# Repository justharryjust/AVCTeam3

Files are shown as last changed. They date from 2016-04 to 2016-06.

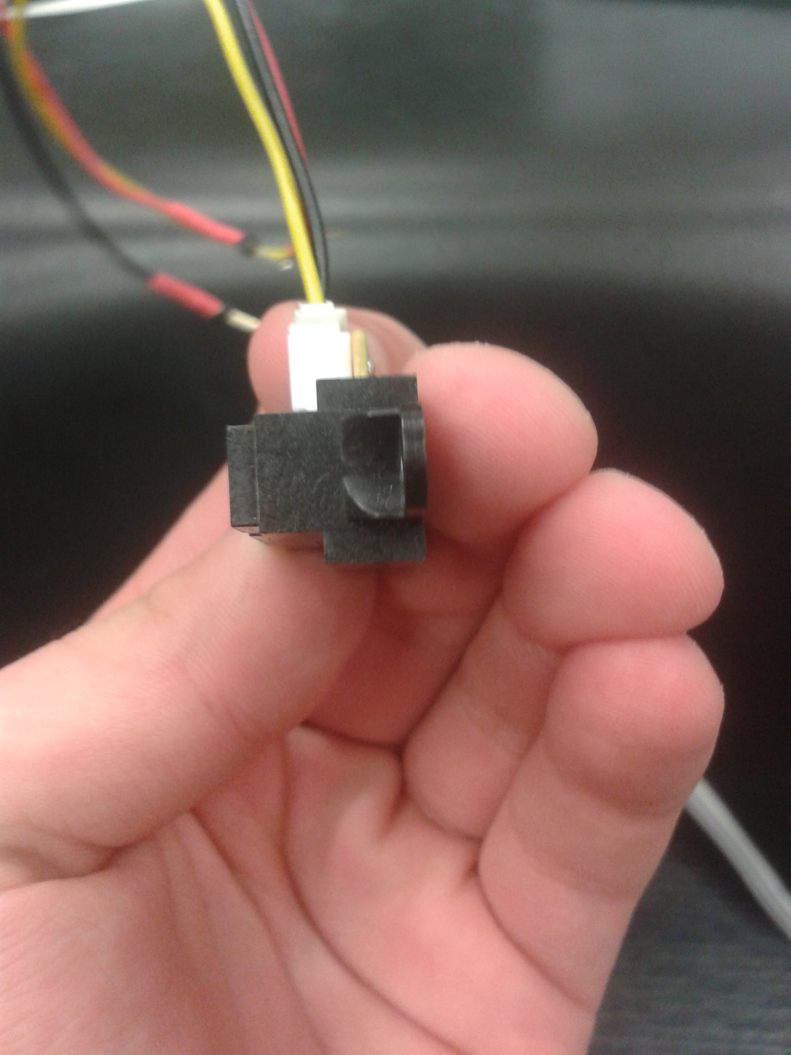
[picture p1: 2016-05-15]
Hardware/sensor2.jpg

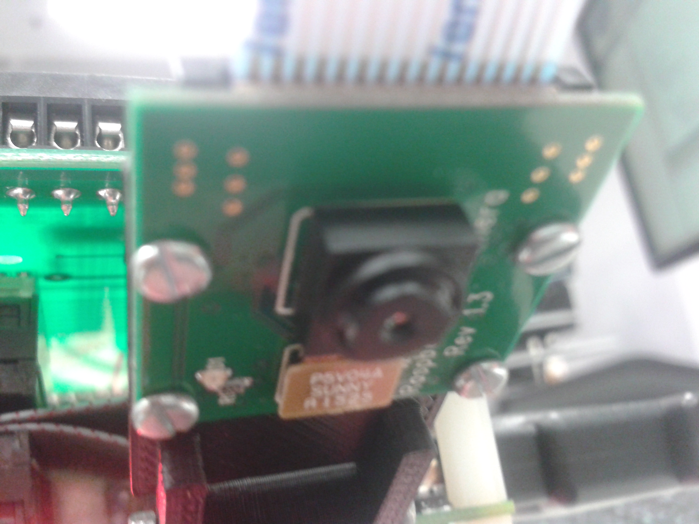
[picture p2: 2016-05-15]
Hardware/camera.jpg

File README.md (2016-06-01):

# AVCTeam3 - Apollo 100
Our project repository for the ENGR101 autonomous vehicle challenge (AVC) 2016.
Members:
- Thomas Edwards - Lead/Manager
- Julian Schurhammer - Software
- Nicky McCleery - Hardware 
- Harry Just - Hardware
- Adam Jiang - Software

###Week 1 Checklist
- [x] Thomas: Write up Plan in proper table
- [x] Thomas: Check all have signed aggreement 
- [x] Thomas: photo of maze uploaded
- [x] Thomas: Research error correction and code for following line
- [x] Julian: Produce code for straight line
- [x] Julian: Research PID and SSH
- [x] Adam: Help out Julian 
- [x] Adam: Research networking communication signal to open gate
- [x] Harry+Thomas: Setup team github repository
- [x] Nicky+Harry: Develop prototype chassis with pi
- [x] Nicky+Harry: Try assemble first prototype
- [x] Everyone: Add each other on facebook and set up group chat

##Week 1 review
Everyone did their assigned tasks, we got a group chat going and everyone successfully showed up to our lab. The initial default robot was assembled and we managed to get the robot's wheels to run successfully. This week hopefully we can get our robot following the line and get the basic robot design sorted. 

##Week 2 Checklist
- [x] Thomas: Review and record progress
- [x] Nicky+Harry: Work on making upgraded chassis prototype 2 which can turn easily (180mm space) and hold sensors
- [x] Julian: Work on code for making robot follow the white line
- [x] Adam: Work on code which will open the network gate
- [x] Thomas: Help work on code or if not needed help with prototype 2
 
##Week 2 review
Week 2 we managed to get the robot to follow the line, but it used the "reverse backwards" method instead of PID so hopefully we can change it in future to use PID. On the hardware side we managed to make some plans for our final robot design, these need to be uploaded to github, and used to write our reports. Networking code managed to be completed but hasnt been tested yet.

##Week 3 Checklist
- [x] Thomas: Review and record progress
- [x] Nicky+Harry: Work on chassis design and try to start building it.
- [x] Julian: Work on code for making robot follow the white line through intersections and turns
- [x] Adam: Finalise and test networking code, ensure it works as expected, try and merge it with line following code
- [x] Thomas: Help work on code or if not needed help with prototype
- Overall robot should: move forward, stop at gate, send network signal, wait till gate is opened, start doing line following code

##Week 3 Review
Week 3 we managed to design all of our hardware additional features including the battery holder, sensor holders and the 3rd ball wheel. We are waiting for the 3D printers to become available so we can print these off. Code wise, our robot now follows the line through the first 2 quadrants successfully using well tuned PID. We have planned out the code for the third quadrant but have yet to test and implement it.

##Week 4 Checklist
- [x] Thomas: Review and record progress
- [x] Harry: Have our marble holder/third wheel printed out and screwed on robot.
- [x] Harry: Create a proper battery holder to hold the battery securely
- [ ] Nicky: Have all our IR sensor holders printed out and screwed on
- [x] Julian: Finish code to make robot completly follow white lines through quadrant 3.
- [x] Thomas: Write code so that robot responds to the walls of maze:
- There are 3 sensors facing the front, left and right. At 45 degree angles
- Robot should follow Right Hand wall to get to the end. (Doesnt have to stop at the end)
- Robot will need to balance itself so that it is always a constant distance from Right wall.
- Robot will need to have a method to turn itself left 90 degrees.
- [x] Thomas: Write full maze code with help from Adam
- [x] Julian: Help with Maze code id line code fully complete

##Week 4 Review
Week 4 we are behind slightly, we have the ball holder but still waiting on the infared sensor holders to be printed or improvised. Changing our thirdwheel had an unexpected setback of changing our line following PID code. Retesting and tweaking this code for the new wheel is well underway and it's able to make it though the first two quadrants again. The code for quadrant three is still being tested and adjusted. The maze code has been written in a first draft but not tested. Extra hours will need to be put in from each team member for the robot to be upto scratch for the day.

##Week 5 The Day.
- [x] Everything should be done. All code merged into single file.
- [ ] No changes made on the day.
- [x] Maze Code all done and working.
- During this weeks lab we will have to show Arthur how far our robot can get through the maze.

##Week 5 Review
Week 5, this week alot of hardwork and effort was put in by the team. The maze code managed to be completed and tested, the hardware was fully completed and everything was securely fastened in place. The hardwork paid off and we managed to make it through 100% of the course on the first try (Amazing), despite our practise runs only making it through about 30% of the time. The only change we made on the day was to uncomment our Network code. Our chassis broke during a test run that went wrong however by using another piece of chassis and some screws we were able to fix it.

##General Plan
 - First Week: Assign Roles, assemble basic robot, get it moving
 - Second Week: Robot moves through gate and in straght lines and turns, (Quadrant 1)
 - Third Week: Robot should be able to follow tape (Quadrant 2)
 - Fourth Week: Robot should be able to follow tape through right angle intersections and turns (Quadrant 3)
 - Fifth Week onwards: Work on Challenge part (Quadrant 4). Finnalise any code/hardware needing work

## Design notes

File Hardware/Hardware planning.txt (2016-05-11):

Hardware design specifications:

Hold the infrared sensors
  Encase the pi and hold it
  Be able to turn in the maze which is 180mm
  Look sleek and cool (optional)
  Be recyclable/relatively environmentally friendly

5mm between the centre of holes
Holes are 3mm each

Objectives
  3d print the ball and holder
  3d print the infared senor holders
  Potentially 3d print a case.

Designs on paper or CAD done by saturday.

Nicky:
  sensor holders
  
Harry:
  ball and holder

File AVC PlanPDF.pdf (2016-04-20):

AVC Plan

Robot name: Apollo 100

Team members and roles (Note. we all plan to help on all things so roles are only a rough guideline):

-Thomas Edwards - Lead/Manager

-Julian Schurhammer - Software

-Nicky McCleery - Hardware

-Harry Just - Hardware

-Adam Jiang – Software

Our full plan and weekly up to date progress can be found on Git hub

Link to Team GitHub: https://github.com/harryJst/AVCTeam3

Week | Dates | Team Objectives | Due | Conflicts | Task outline
1 | 18April | Organise everything | 22 April AVC PLAN | Phys 122 test | • Thomas- Organise things and set up Git Page • Julian - Write test code for moving robot • Nicky & Harry - Build first chassis • Adam - Gather info on networking gate • Everyone- Facebook and group chat
Holiday | 25April | Finish off Week 1 tasks if not done
2 | 2May | Have the robot moving through networking gate | | | • Thomas- Review and write up progress & help • Julian - Write test code for following white line • Nicky & Harry - Work on upgrading chassis • Adam - Write code for networking gate
3 | 9May | Have the robot chassis design finalised and have the robot following white line Quadrant 2 complete | | Comp 102 test | • Thomas- Review and write up progress & help • Julian - Write test code for turning with white line • Nicky - Work on chassis or help with code • Harry - Work on chassis or help with code • Adam - Help with code for turning and overcoming intersections
4 | 16May | Quadrant 3 complete | Progress Report | ENGR 121 test | • Update results, work on quadrant 3
5 | 23May | Quadrant 4 complete | | | • Update results, work on quadrant 4
6 | 30May | Everything complete | ROBOT due | ENGR 101 test | • Update results, work on anything if behind
7 | 6June
8 | 13June | | Final Report due

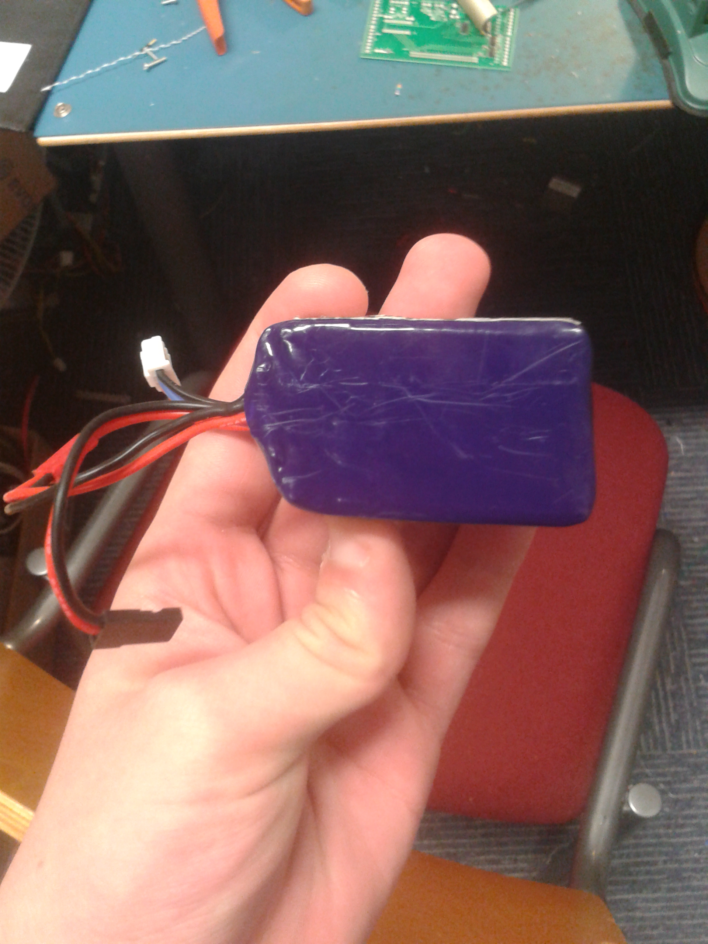
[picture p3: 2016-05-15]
Hardware/battery2.jpg

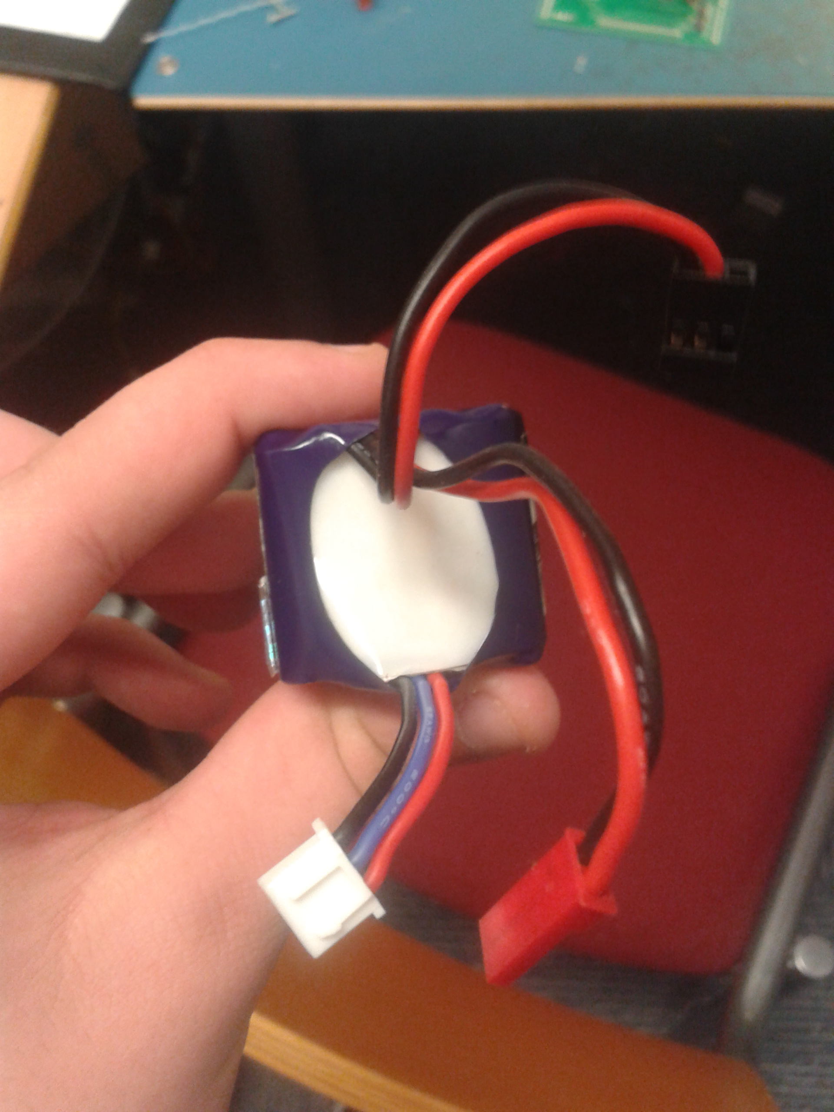
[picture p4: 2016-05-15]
Hardware/battery1.jpg

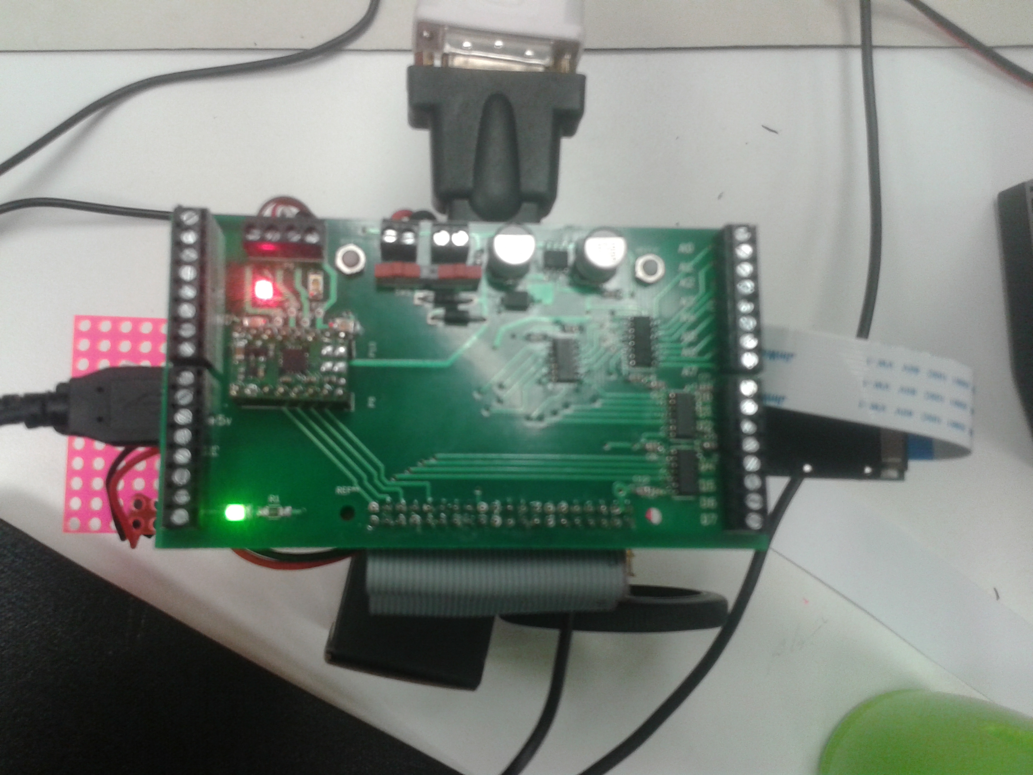
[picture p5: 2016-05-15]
Hardware/toprobot.jpg

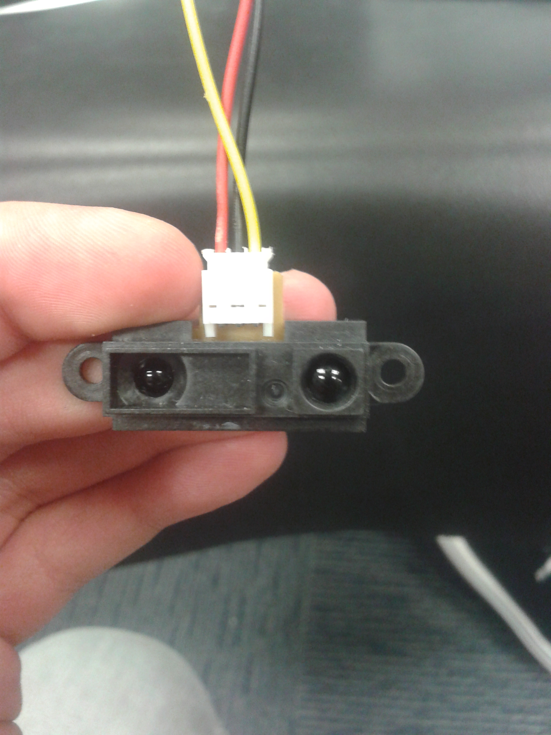
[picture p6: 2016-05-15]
Hardware/sensor1.jpg

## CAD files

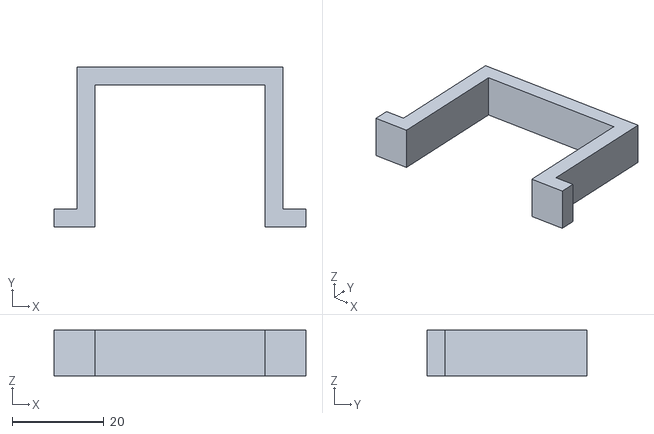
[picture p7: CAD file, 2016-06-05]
Hardware/Final_Battery_holder.stl
55.0 x 35.0 x 10.0

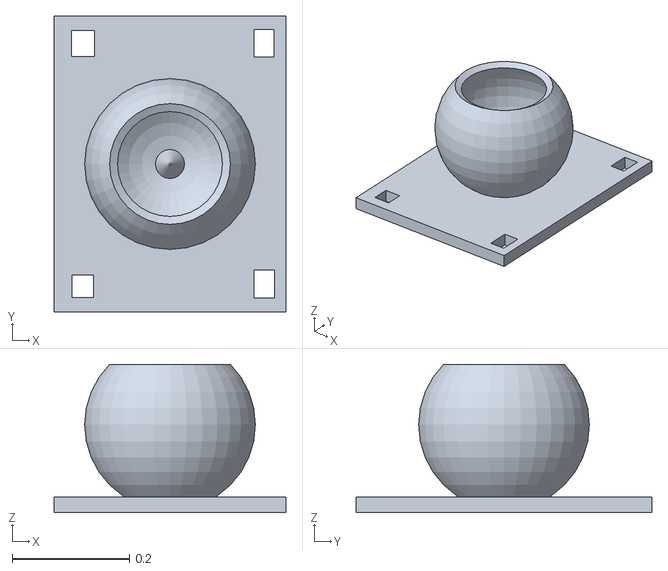
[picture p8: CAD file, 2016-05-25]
Pictures/WHEEL_HOLDER.stl
0.395 x 0.504 x 0.253

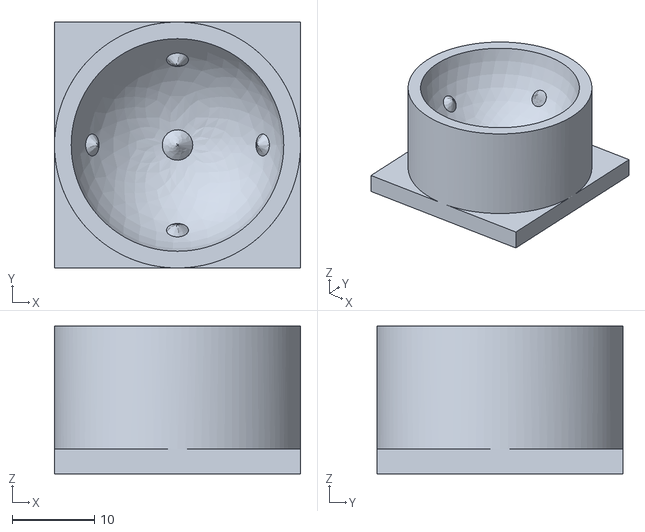
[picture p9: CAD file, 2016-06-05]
Hardware/mesh_to_print_wheel.stl
30.0 x 30.0 x 18.0

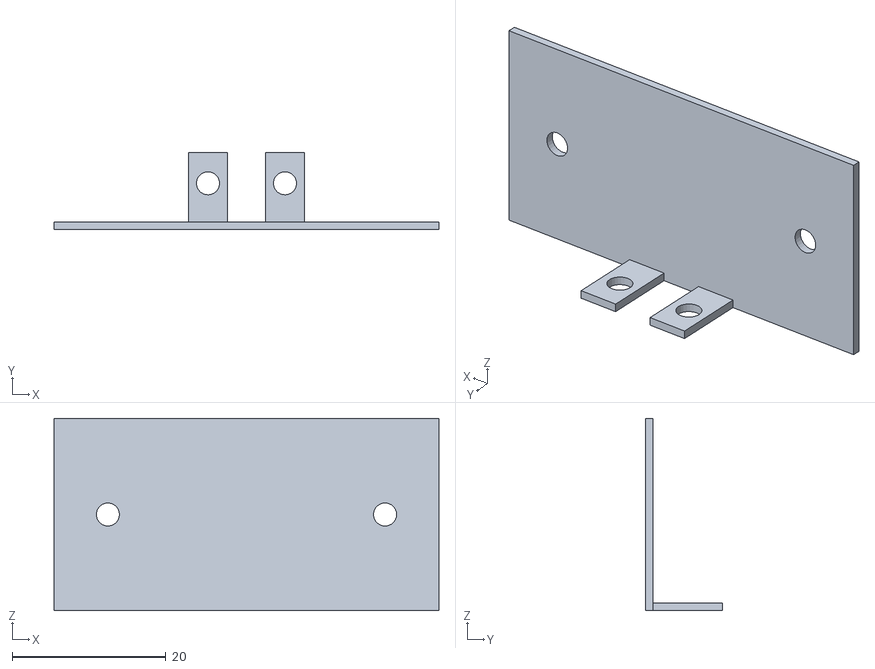
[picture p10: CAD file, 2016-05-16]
Pictures/IR sensorHolderV2.stl
50.0 x 10.0 x 25.0

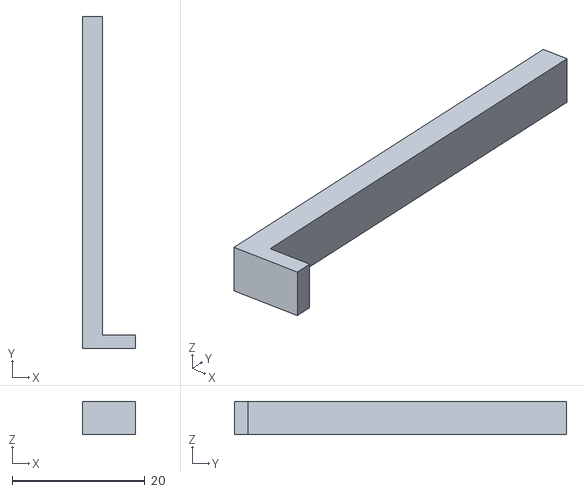
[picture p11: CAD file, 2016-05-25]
Hardware/Lbracket.stl
8.00 x 50.0 x 5.00

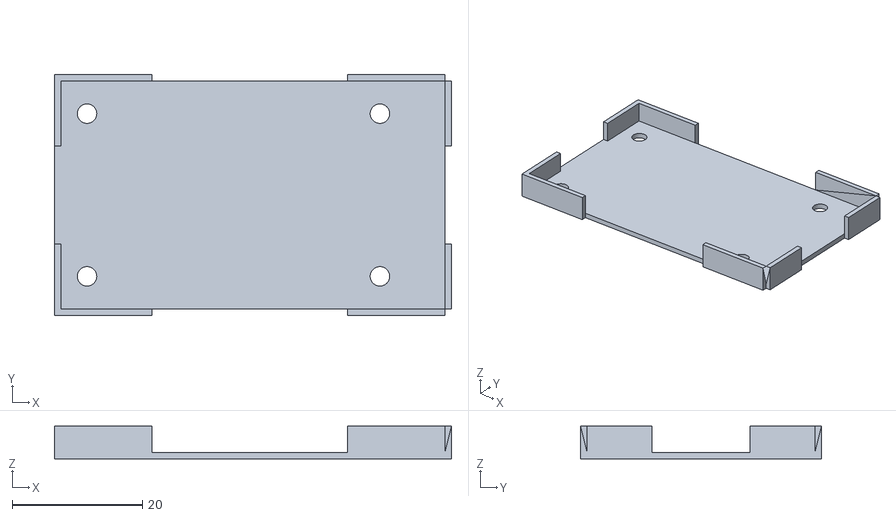
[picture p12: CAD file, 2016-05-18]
Hardware/Batt Holder.stl
61.0 x 37.0 x 5.00

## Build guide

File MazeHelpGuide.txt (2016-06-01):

How the maze code Starts:

The maze code is initialised when the right hand sensor detects an object closer than about 5cm. To avoid this triggering when 
going through the network gate, there is also a counter which moves up every time the robot moves. Only once the robot has moved
about halfway through the course will it start taking readings from the sensors.

How the maze code works:

Maze code is quite simple, there are only  two sections of it. The first section is a loop which loops forever, this loop simply 
takes a distance reading of the right hand wall,  does some math (subtracts 400 then multiplies by 0.15) and sets the motors to that 
resulting number. If the number is positive then the left motor will move more than the right and if negative vice versa. This code 
enables the robot to follow the right hand wall through straight paths and also right turns (as when no wall is detected on the right,
resulting number becomes very negative causing a sharp right turn until a wall is detected again).
The second piece of code is simply a hard coded left turn method, it is called whenever the front sensor detects a wall closer than 5cm. 
It simply codes the left wheel to stop and the right wheel to spin for 0.7 seconds which creates a perfect left turn. The code then 
returns to following the right wall.

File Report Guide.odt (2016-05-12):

Report

guide here:

https://github.com/kaiwhata/ENGR101-2016/wiki/Report-Writing-guide

Aim: To build a functioning robot that will follow a white line through curves and intersections, it will then get to a maze section without a white line and successfully navigate its way to the end of the maze.

Possible Motivations:

Practise working in a team

Beat other teams.

Gain skills in working on long term projects such as time managing, breaking tasks up etc.

Increase communications skills.

Good grades

Self fulfilment.

Software:

Problem to be solved:

- Robot loses the line when it oscillates when following it, and then keeps going forward. As error signal is 0 when all black.
  What we’ve done:
- Takes all pixels along one line, puts them into an array
- if the greyscale of the pixels are darker than a certain value, then they are black otherwise they are white.
- Amount of whiteness which is detected that is not centred will create a plus/minus error signal
- Error signal is used to control speed of each wheel. So that it turns proportionate to how off centred line is.
- Implemented PID into code to follow line. Haven’t managed to get it working perfectly yet.

Hardware:

3d printing complex shapes harder than expected

Built basic chassis so that code can be tested before final model is built

Sketches for cases done, best design still to be chosen

Model for back wheel/ball designed, temporary marble in place atm

Camera held securely in place at front so that there isn’t any jiggling when robot moving

Using large wheels (pros/cons)

Network:

Written code to open gate through wifi.

Need to write code to use sensor to stop/start when gate closed/open

This code possibly can be used in the maze as well.

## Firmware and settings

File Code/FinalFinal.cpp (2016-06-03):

#include<iostream> 
#include<stdio.h> 
#include<time.h> 
#include<chrono> 
#include<cstdlib> 
#include<signal.h>

extern "C" int init(int d_level);
extern "C" int Sleep(int sec, int usec);
extern "C" int set_motor(int motor, int value);
extern "C" int take_picture();
extern "C" int get_pixel(int row, int col, int colour);
extern "C" int open_screen_stream();
extern "C" int close_screen_stream();
extern "C" int update_screen();
extern "C" int connect_to_server(char server_addr[15], int port);
extern "C" int send_to_server(char message[24]);
extern "C" int receive_from_server(char message[24]);
extern "C" int read_analog(int ch_adc);
extern "C" int set_pixel(int row, int col, char red, char green, char blue);

using namespace std;
using namespace std::chrono;

const int white_value = 110;
const int camera_y_coord = 0;
const int min_line_width = 25;
const float speed = 0.9; // working value 0.9
const int speed1 = 60; // speed for maze code
bool run_sensor = true;
float P = 0.28; // working value 0.28
float I = 0.0; // working value 0.0
float D = 50; // working value 50
float max_error = 160; // working value 160

// This method is called when the program exists
void signal_callback_handler(int signum)
{
    set_motor(1, 0);
    set_motor(2, 0);
    exit(signum);
}

// Return the error signal from the current picture
int error_method_4(int cam_y)
{
    int min = 0;
    int consec_white_pixels = 0;
    for (int i = 0; i < 320; i++) { // Loop through line of pixels at given y coord
        int value = get_pixel(i, cam_y, 3);
        if (value > white_value) { // If the pixel is white
            consec_white_pixels += 1; // Increate the consecutive pixel counter
            if (consec_white_pixels >= min_line_width) { // If there are enough white pixels
                min = i - consec_white_pixels; // Set min to where the consecutive pixels started
                break; // Stop the loop
            }
        }
        else { // If the pixel is black
            consec_white_pixels = 0; // Reset the pixel counter
        }
    }
    int max = 0;
    consec_white_pixels = 0;
    for (int i = 320; i >= 0; i--) { // Loop through the line of pixels again, this time 
        int value = get_pixel(i, camera_y_coord, 3); // back to front
        if (value > white_value) { // if the pixels is white
            consec_white_pixels += 1; // increate the counter
            if (consec_white_pixels >= min_line_width) { // if the counter is big enough
                max = i + consec_white_pixels; // Set min to where the consecutive pixels started
                break; // Stop the loop
            }
        }
        else { // If pixel si black
            consec_white_pixels = 0; // Reset the pixel counter
        }
    } 
    // Return the average of the min and max point of the line, ie the middle,
    // and set subtract 160 so that the signal is 0 in the center of the picture,
    return ((min + max) / 2) - 160; // -ive to the left and +ive to the right.
}

// Restrict val between a and b
int clamp(int a, int b, int val)
{
    if (val < a) {
        return a;
    }
    if (val > b) {
        return b;
    }
    return val;
}

// Return the current time stamp in miliseconds as a long
long get_time()
{
    return duration_cast<milliseconds>(system_clock::now().time_since_epoch()).count();
}

// Draw what the camera is seeing on screen in black & white
void print_picture()
{
    for (int i = 0; i < 240; i++) {
        for (int j = 0; j < 320; j++) {
            int value = get_pixel(j, i, 3);
            if (value > white_value) {
                set_pixel(j, i, 255, 255, 255);
            }
            else {
                set_pixel(j, i, 0, 0, 0);
            }
            if (i == 0) {
                set_pixel(j, i, 200, 0, 0);
            }
        }
    }
    update_screen();
}

// Return true if there is a sharp right turn
bool line_on_right()
{
    int white_pixels = 0;
    for (int i = 0; i < 160; i++) { // Loop from the right to the middle of the picture
        int value = get_pixel(i, camera_y_coord, 3);
        if (value > white_value) { // if the pixel is white
            white_pixels += 1; // add to the pixel counter
        }
        if (white_pixels > 150) { // if 150/160 pixels are white
            return true; // there is a sharp right turn, return true
        }
    }
    return false; // return false otherwise
}

// Return true if there is a sharp left turn
bool line_on_left()
{
    int white_pixels = 0;
    for (int i = 160; i < 320; i++) { // Loop from the middle to the left of the picture
        int value = get_pixel(i, camera_y_coord, 3);
        if (value > white_value) { // if the pixel is white
            white_pixels += 1; // add to the pixel counter
        }
        if (white_pixels > 150) { // if 150/160 pixels are white
            return true; // there is a sharp left turn, return true
        }
    }
    return false; // return false otherwise
}

// Return true the robot is at an intersection
bool is_at_intersection()
{
    int white_pixels = 0;
    for (int i = 0; i < 320; i++) { // Loop through a line on the picture
        int value = get_pixel(i, camera_y_coord, 3);
        if (value > white_value) { // if the pixel is white
            white_pixels += 1; // add to the pixel counter
        }
        if (white_pixels > 300) { // if 300/320 pixels are white
            return true; // there is an intersection, return true
        }
    }
    return false; // return false otherwise
}

// Return true if there is a line to make an error signal
bool is_line_there(int camera_y)
{
    int consec_white_pixels = 0;
    for (int i = 0; i < 320; i++) { // Loop through a line on the picture
        int value = get_pixel(i, camera_y, 3);
        if (value > white_value) { // if the pixel is white
            consec_white_pixels += 1; // add to consecutive pixel counter
            if (consec_white_pixels >= min_line_width) { // if the counter is big enough
                return true; // return true, there is a line there
            }
        }
        else { // if the pixel is black
            consec_white_pixels = 0; // reset the counter
        }
    }
    return false;
}

int integral = 0;
int last_error = 0;
long last_loop_end_time = 0;
// Do one iteration of the line following code
void follow_loop()
{
    take_picture(); // Take a new picture
    int error = 0;
    if (is_line_there(camera_y_coord)) { // if there is a line
        error = error_method_4(camera_y_coord); // get the error signal from that line
    }
    else { if there is no line (lost the line)
        if (last_error > 0) { // if the last error was > 0
            error = max_error; // set the error to the maximum error
        }
        else { // otherwise
            error = 0 - max_error; // set the error to negative of the maximum error
        }
    }
    if (is_at_intersection()) { // If the robot is at an intersection
        if (is_line_there(220 /*220 = pixel near top */)) { 
            //If there is a going line forward
            error = error_method_4(220); // get error based on that line
        }
        else { // otherwise
            error = max_error; //go left
        }
    }
    else if (line_on_left()) {// If the robot is at a sharp left turn
        if (is_line_there(220 /*220 = pixel near top */)) {
            error = error_method_4(220); // get error based on that line
        }
        else { // otherwise
            error = max_error; //go left
        }
        error = max_error;
    }
    else if (line_on_right()) { // If the robot is at a sharp right turn
        if (is_line_there(220 /*220 = pixel near top */)) {
            error = error_method_4(220); // get error based on that line
        }
        else { // otherwise
            error = 0 - max_error; //go right
        }
    }
    print_picture(); // print out the current picture
    integral += error; // the integral is the runing total of errors
    long time = get_time(); // get the current timestamp
    // The derivative is change in error over change in time
    float derivitive = ((float)(error - last_error)) / ((float)(time - last_loop_end_time));
    last_loop_end_time = time; // set the last end time to the current time
    last_error = error; // set last error to current error
    int final_signal = P * error + I * integral + D * derivitive; // make the final signal using PID constants
    cout << "error " << error << endl; // print out the error for debugging
    cout << "integral " << integral << endl; // print out the integral for debugging
    cout << "derivitive " << derivitive << endl; // print out the derivitive for debugging
    cout << "final " << final_signal << endl; // print out the final signal for debugging
    // set the motor speeds to a value that iss  50 +- the final signal, but also between -100 and 150
    set_motor(1, speed * clamp(-100, 150, 50 + final_signal));
    set_motor(2, speed * clamp(-100, 150, 50 - final_signal));
}

// main method, run when the program is started
int main()
{
    init(0); // initialise the e101 library
    open_screen_stream(); // open the stream for printing the picture on the screen

    connect_to_server("130.195.6.196", 1024); // connect to the gate server
    send_to_server("Please"); // send "Please" to the gate sever
    char pswd[24]; // Create a char array to store the password
    receive_from_server(pswd); // Get the password from the sever and store it
    send_to_server(pswd); // Send the password back to the server

    int count = 0; // a counter for delaying the activation of the maze code
    last_error = error_method_4(0); // initialise the last error variable
    last_loop_end_time = get_time(); // initialise the loop end time variable
    while (true) { // repeat forever
        int sen3 = read_analog(2); // read the right ir sensor
        int sen1 = read_analog(1); // read the left ir sensor
        int sen2 = read_analog(0); // read the middle ir sensor
        count++;
        if (sen3 < 300 && sen1 < 300) { // if the sensors dont see anythign close
            follow_loop(); //follow the line
        }
        else if (sen2 > 300) { // if the middle sensor seed something close
            set_motor(1, 0); // stop the motor
            set_motor(2, 0); // stop the other motor
            last_loop_end_time = get_time(); // set the last loop time
        }
        else if ((sen3 > 400 || sen1 > 400) && sen2 < 300 && count > 200) {
            while (1) {
                int sen1 = read_analog(1); // read the left ir sensor
                int sen2 = read_analog(0); // read the middle ir sensor
                int sen3 = read_analog(2); // read the right ir sensor

                int dif = sen3 - 400; //distance from right hand wall (Smaller is a great distance)
                if (dif < -220) {
                    dif = -220;
                } //sharpness of turn (smaller is less sharp)
                dif = dif * 0.15; //how responsive robot is
                set_motor(1, speed1 + dif);
                set_motor(2, speed1 - dif);

                if (sen2 > 220 && sen3 > 200) { //turning Left method
                    set_motor(1, 0);
                    set_motor(2, 0);
                    Sleep(1, 0);
                    set_motor(1, speed1 + 40); //speed of turn
                    set_motor(2, 0);
                    Sleep(0, 600000); //turn duration
                }
            }
        }
    }

    return 0;
}

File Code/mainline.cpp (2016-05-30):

#include <iostream>
#include <stdio.h>
#include <time.h>
#include <chrono>

extern "C" int init(int d_level);
extern "C" int Sleep(int sec, int usec);
extern "C" int set_motor(int motor, int value);
extern "C" int take_picture();
extern "C" int get_pixel(int row, int col, int colour);
extern "C" int open_screen_stream();
extern "C" int close_screen_stream();
extern "C" int update_screen();
extern "C" int connect_to_server( char server_addr[15],int port);
extern "C" int send_to_server(char message[24]);
extern "C" int receive_from_server(char message[24]);
extern "C" int read_analog(int ch_adc);
extern "C" int set_pixel(int row, int col, char red, char green, char blue);

using namespace std;
using namespace std::chrono;

//PID coefficients
const float P = 0.28;
const float I = 0.0;
const float D = 50;

//Other constants
const int white_value = 110;
const int min_line_width = 40;
const float speed = 0.9;

//Restrict val between a and b
int clamp(int a, int b, int val){
	if(val < a){
		return a;
	}
	if(val > b){
		return b;
	}
	return val;
}

long get_time(){
	return duration_cast<milliseconds>(system_clock::now().time_since_epoch()).count();
}

void print_picture(){
	for(int i = 0; i < 240; i++){
		for(int j = 0; j < 320; j++){
			int value = get_pixel(j, i, 3);
			if(value > white_value){
				set_pixel(j, i, 255, 255, 255);
			} else {
				set_pixel(j, i, 0, 0, 0);
			}
		}
	}
	update_screen();
}

int get_error(int y_value){
	int min = 0;
	int consec_white_pixels = 0;
	for(int i = 0; i < 320; i++){
		int value = get_pixel(i, y_value, 3);
		if(value>white_value){
			consec_white_pixels += 1;
			if(consec_white_pixels >= min_line_width){
				min = i - consec_white_pixels;
				break;
			}
		}
		else {
			consec_white_pixels = 0;
		}
	}
	int max = 0;
	consec_white_pixels = 0;
	for(int i = 320; i >=0; i--){
		int value = get_pixel(i, y_value, 3);
		if(value>white_value){
			consec_white_pixels += 1;
			if(consec_white_pixels>=min_line_width){
				max = i + consec_white_pixels;
				break;
			}
		} else {
			consec_white_pixels = 0;
		}
	}
	return ((min + max)/2)-160;
}

bool vertical_line(int y_coord){
	int consec_white_pixels = 0;
	for (int i = 0;i<320;i++) {
		int value = get_pixel(i, y_coord, 3);
		if (value>white_value) {
			consec_white_pixels += 1;
			if(consec_white_pixels >= min_line_width){
				return true;
			}
		} else {
			consec_white_pixels = 0;
		}
	}
	return false;
}

bool is_intersection(int y_coord){
	int consec_white_pixels = 0;
	for (int i = 0;i<320;i++) {
		int value = get_pixel(i, y_coord, 3);
		if (value>white_value) {
			consec_white_pixels += 1;
			if(consec_white_pixels >= 200 /* 200 = 80% are white*/){
			return true;
		}
	} else {
		consec_white_pixels = 0;
	}
}
return false;
}

bool horizontal_line(int x_coord){
	int consec_white_pixels = 0;
	for (int i = 0;i<240;i++) {
		int value = get_pixel(x_coord, i, 3);
		if (value>white_value) {
			consec_white_pixels += 1;
			if(consec_white_pixels >= min_line_width){
				return false;
			}
		} else {
			consec_white_pixels = 0;
		}
	}
	return true;
}



//Initial values
int integral = 0;
int last_error = 0;
long last_loop_end_time = 0;
void follow_line(){
	take_picture();

	print_picture();
	if(is_intersection(0)){
		if(vertical_line(230 /* 230y = top pixel */)){

		} else if (horizontal_line(0 /* 0x = left pixel */)){

		} else if (horizontal_line(310 /* 310x = top pixel */)){

		}
	} else if(vertical_line(0 /* 0y = bottom pixel */);){
		//if there is a lineon the bottom pixel, get the error from it
		int error = get_error(0 /* 0 = bottom pixel */);
	} else {
		//lost the line
		error = last_error;
	}

	integral += error;
	long time = get_time();
	float derivitive = ((float)(error - last_error))/((float)(time - last_loop_end_time));
	last_loop_end_time = time;
	last_error = error;

	int final_signal = P*error + I*integral + D*derivitive;

	//Remove clamp?
	set_motor(1 , speed*clamp(-100, 150, 50+final_signal));
	set_motor(2 , speed*clamp(-100, 150, 50-final_signal));
}

int main()
{
	init(0);
	open_screen_stream();

	//    connect_to_server("130.195.6.196",1024);
	//    send_to_server("Please");
	//    char pswd[24];
	//    receive_from_server(pswd);
	//    send_to_server(pswd);

	int adc_reading = 0;
	last_error = get_error();
	last_loop_end_time = get_time();
	while(true){
		adc_reading = read_analog(0);
		if(adc_reading<400){
			//Follow the line
			follow_line();
		} else {
			//Stop
			set_motor(1 , 0);
			set_motor(2 , 0);
			last_loop_end_time = get_time();
		}
	}
	return 0;
}

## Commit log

2016-05-04 Camera test
2016-05-05 Code tested, follows line, gets stuck occasionally
    Next step is make robot adjust its direction slightly when it move backward, possibly just random adjustment or adjustment based on whether it lost line to the left or the right.
    [tom camera test.cpp]
2016-05-05 when reversing, it turns slightly
    updated code so that when it moves backwards it turns slightly. This should prevent it from getting stuck
    [tom camera test.cpp]
2016-05-16 IR Sensor Mounting Bracket
    [IR Hplder v2.stl]
2016-05-18 Create 3d printing
2016-05-18 3d printing parts
    [Batt Holder.stl, IR Hplder v2.stl]
2016-05-18 new PID code
2016-05-25 Add files via upload
    final hardware parts
    [Lbracket.stl, WHEEL_HOLDER.stl]
2016-05-30 Cleaned up files
    [Batt Holder.stl, IR Hplder v2.stl, Lbracket.stl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]
2016-05-30 Updated more names
    [IR sensorHolderV2.stl]
2016-06-05 Final back wheel design
    the final design that was printed for the robot
    [mesh_to_print_wheel.stl]
2016-06-05 Final Battery holder design
    [Final_Battery_holder.stl]
2016-06-05 Sensor holder Final design
    [Lbracket.stl]
2016-06-05 create summary for sensor and wheel mount
